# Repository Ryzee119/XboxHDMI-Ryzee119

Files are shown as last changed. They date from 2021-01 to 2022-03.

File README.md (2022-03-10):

# Original Xbox 100% Digital HDMI (Prototype)

**Note: This is a 'working' but unfinished prototype. I don't plan to improve this further. See https://makemhz.com/products/xboxhd for a properly finished product with way more features.**

* A few HDMI captures taken from this board are here: https://imgur.com/a/OkmB1Vs
* This is a prototype 100% digital Original Xbox HDMI addon PCB. It taps into the GPU pixel bus before it enters the analog video encoder and converts it to a HDMI compliant signal.
* It has not been fully tested and may not work for you. Use at your own risk. This should only really be a starting point to make something better.
* SPDIF digital audio is tapped off the Xbox motherboard and is also encoded into the HDMI signal for the best possible audio quality.
* This is a prototype board which should work on all Xbox revisions however a new flex would need to be designed to accomodate v1.6 motherboards with an Xcalibur encoder.
* 480i does not work reliably. Use a force 480p BIOS.
* The xbox kernels video modes are not compliant to proper HDMI signalling (v/hsync, porch delays etc). This does not have the ability to correct that. If your display is picky it may just not display anything.
* Currently the MakeMHz solution is recommended. https://makemhz.com/products/xboxhd. It is a completely independent design which has been much more tested and with more features.

## Bill of materials
* See [Kitspace](https://kitspace.org/boards/github.com/ryzee119/XboxHDMI-Ryzee119/).
* Flatflex must be ordered separately. See [hardware](./hardware).

## Design Files
* Source code for the STM32F0 driver is [here](./src).
* Hardware design files are [here](./hardware).

## Programming
* Compile the code with [VSCode](https://code.visualstudio.com/) and the [platformIO](https://platformio.org/install/ide?install=vscode) plugin. It should automatically create the build sytem. Just click build.
* The STM32F07 driver must be programmed with the firmware.
* Programming is through the 5 pin SWD header on the PCB. Pinout from left to right: `+3V3, SWDCLK, GND, SWDIO, NRST`
* Some debug output is via the pad labelled `TX`. Baud 115200.

## Installation

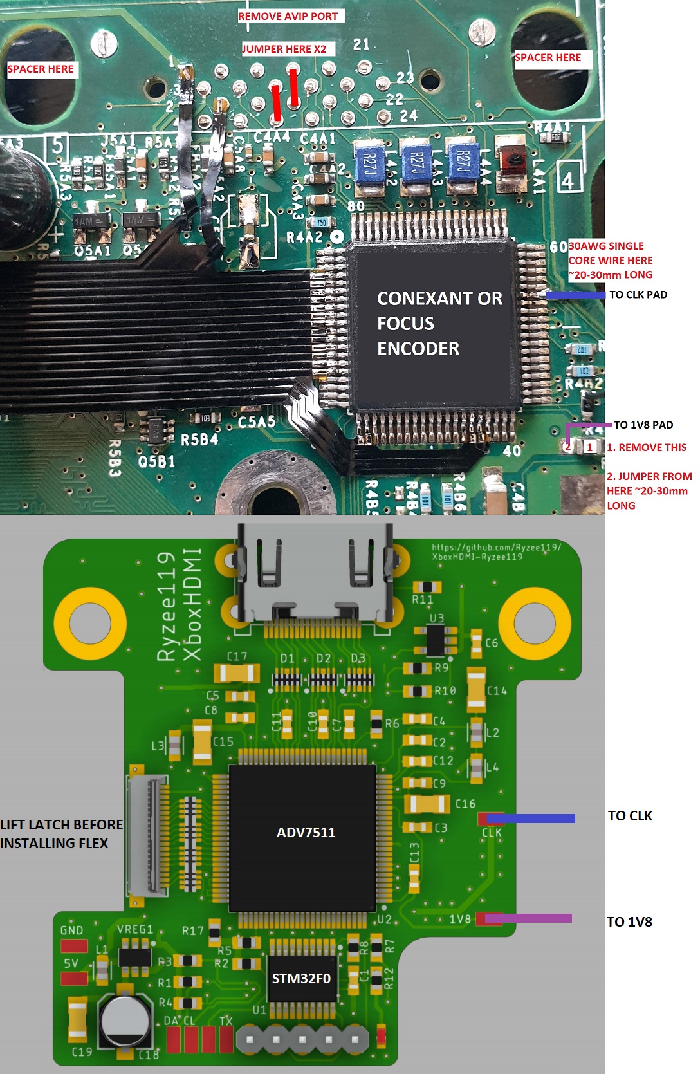
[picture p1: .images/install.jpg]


* Photo may not match final PCB layout.
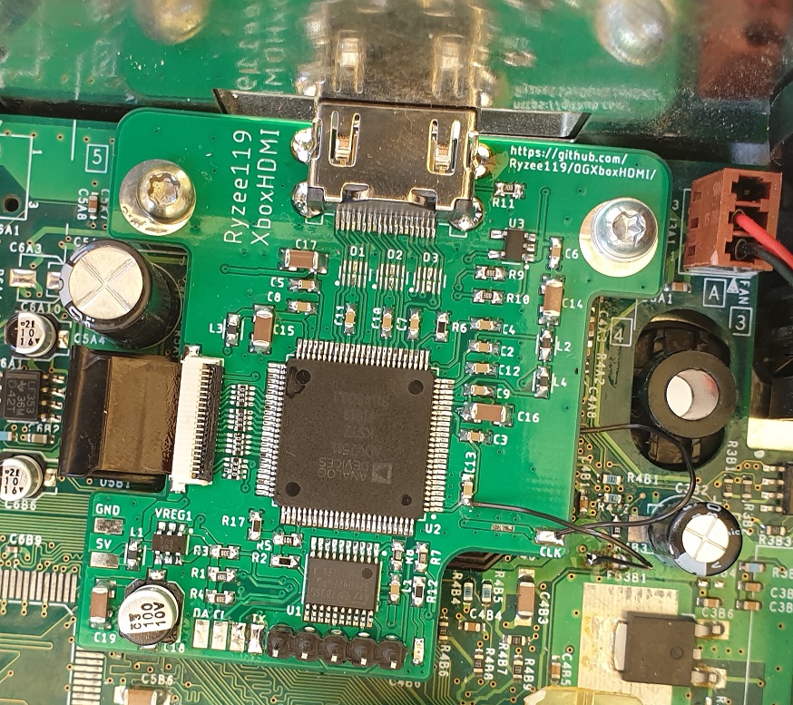
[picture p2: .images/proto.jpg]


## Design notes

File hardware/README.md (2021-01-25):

# Hardware

* This board was designed using [Autodesk Eagle](https://www.autodesk.com/products/eagle/overview). You can edit the `.brd` and `.sch` with this program.

## View Gerbers
* [XboxHDMI PCB](https://tracespace.io/view/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)
* [FlatFlex PCB](https://tracespace.io/view/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)

## View Board and Schematic
* [Board](https://a360.co/3of4zFJ)
* [Schematic](https://a360.co/2LYpuQg)

## 3D Render
* [Fusion 360](https://a360.co/2KIBkxm)

### Flat Flex Properties
* 2 Layers
* Polyimide Flex
* FPC Thickness: 0.10 mm
* Stiffener: BOTTOM Plastic : 0.20 mm , BOTTOM Fr4 : 0 mm , BOTTOM Metal : 0 mm
* Total thickness at stiffener should be 0.30 mm.
* Stiffener location: See image 

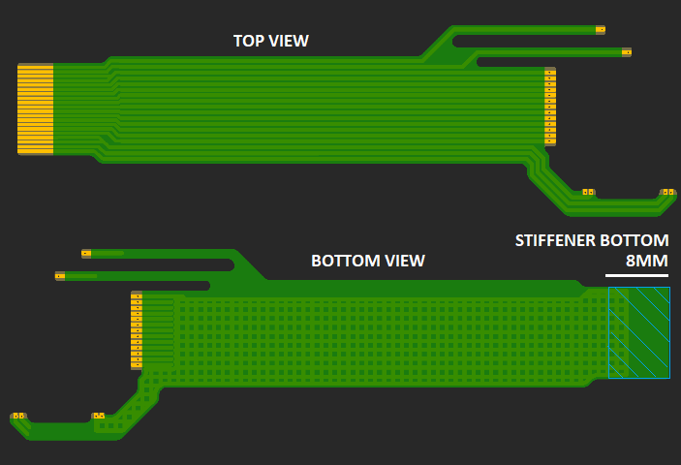
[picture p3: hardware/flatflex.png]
schematic


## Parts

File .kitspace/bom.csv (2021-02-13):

Reference | Qty | Description | Part Number | Manufacturer | Digikey
C1, C2, C3, C4, C5, C6, C7, C8, C9, C10, C11, C12, C13 | 50 | CAP CER 0.1UF 50V X7R 0603 | CL10B104KB8NNNC | Samsung Electro-Mechanics | 1276-1000-1-ND
C14, C15, C16, C17, C19 | 10 | CAP CER 10UF 16V X5R 1206 | C3216X5R1C106M160AA | TDK Corporation | 445-1426-1-ND
C18 | 1 | CAP ALUM 100UF 20% 10V SMD | UWR1A101MCL1GB | Nichicon | 493-14561-6-ND
D1, D2, D3 | 5 | TVS DIODE 5V 15V SLP2510P8 | RCLAMP0524PATCT | Semtech Corporation | RCLAMP0524PACT-ND
J1 | 1 | CONN FFC FPC 20POS 0.50MM R/A | 5034802000 | Molex | WM1445CT-ND
J2 | 1 | CONN RCPT 1.4 HDMI 19POS SMD R/A | 10029449-111RLF | Amphenol ICC (FCI) | 609-4614-1-ND
JP1 | 1 | CONN HEADER VERT 5POS 2.54MM | PH1-05-UA | Adam Tech | 2057-PH1-05-UA-ND
L1, L2, L3, L4 | 10 | FERRITE BEAD 220 OHM 0603 1LN | MPZ1608S221ATA00 | TDK Corporation | 445-1565-1-ND
LED1 | 5 | LED GREEN CLEAR 0603 SMD | 150060VS75000 | Würth Elektronik | 732-4980-1-ND
R1, R3, R4, R7, R8, R9, R10, R11 | 50 | RES SMD 2K OHM 1% 1/10W 0603 | ERJ-3EKF2001V | Panasonic Electronic Components | P2.00KHCT-ND
R13, R14, R15, R16 | 10 | RES ARRAY 4 RES 33 OHM 0804 | YC124-JR-0733RL | Yageo | YC124J-33CT-ND
R2, R6, R12, R17 | 50 | RES SMD 887 OHM 1% 1/10W 0603 | ERJ-3EKF8870V | Panasonic Electronic Components | P887HCT-ND
R5 | 50 | RES 100 OHM 1% 1/10W 0603 SMD | ERJ-U03F1000V | Panasonic Electronic Components | 10-ERJ-U03F1000VCT-ND
SPACER | 4 | ROUND SPACER 3MM HEIGHT | 005419000014 | Essentra Components | RPC3399-ND
U1 | 1 | IC MCU 32BIT 32KB FLASH 20TSSOP | STM32F070F6P6TR | STMicroelectronics | 497-17354-1-ND
U2 | 1 | ADV7511 | ADV7511KSTZ | Analog Devices
U3 | 1 | IC PWR SWITCH P-CHAN 1:1 SOT23-5 | MIC2091-1YM5-TR | Microchip Technology | 576-3891-1-ND
VREG1 | 1 | IC REG LINEAR 1.8V/3.3V SOT26 | AP7312-1833W6-7 | Diodes Incorporated | AP7312-1833W6-7DICT-ND

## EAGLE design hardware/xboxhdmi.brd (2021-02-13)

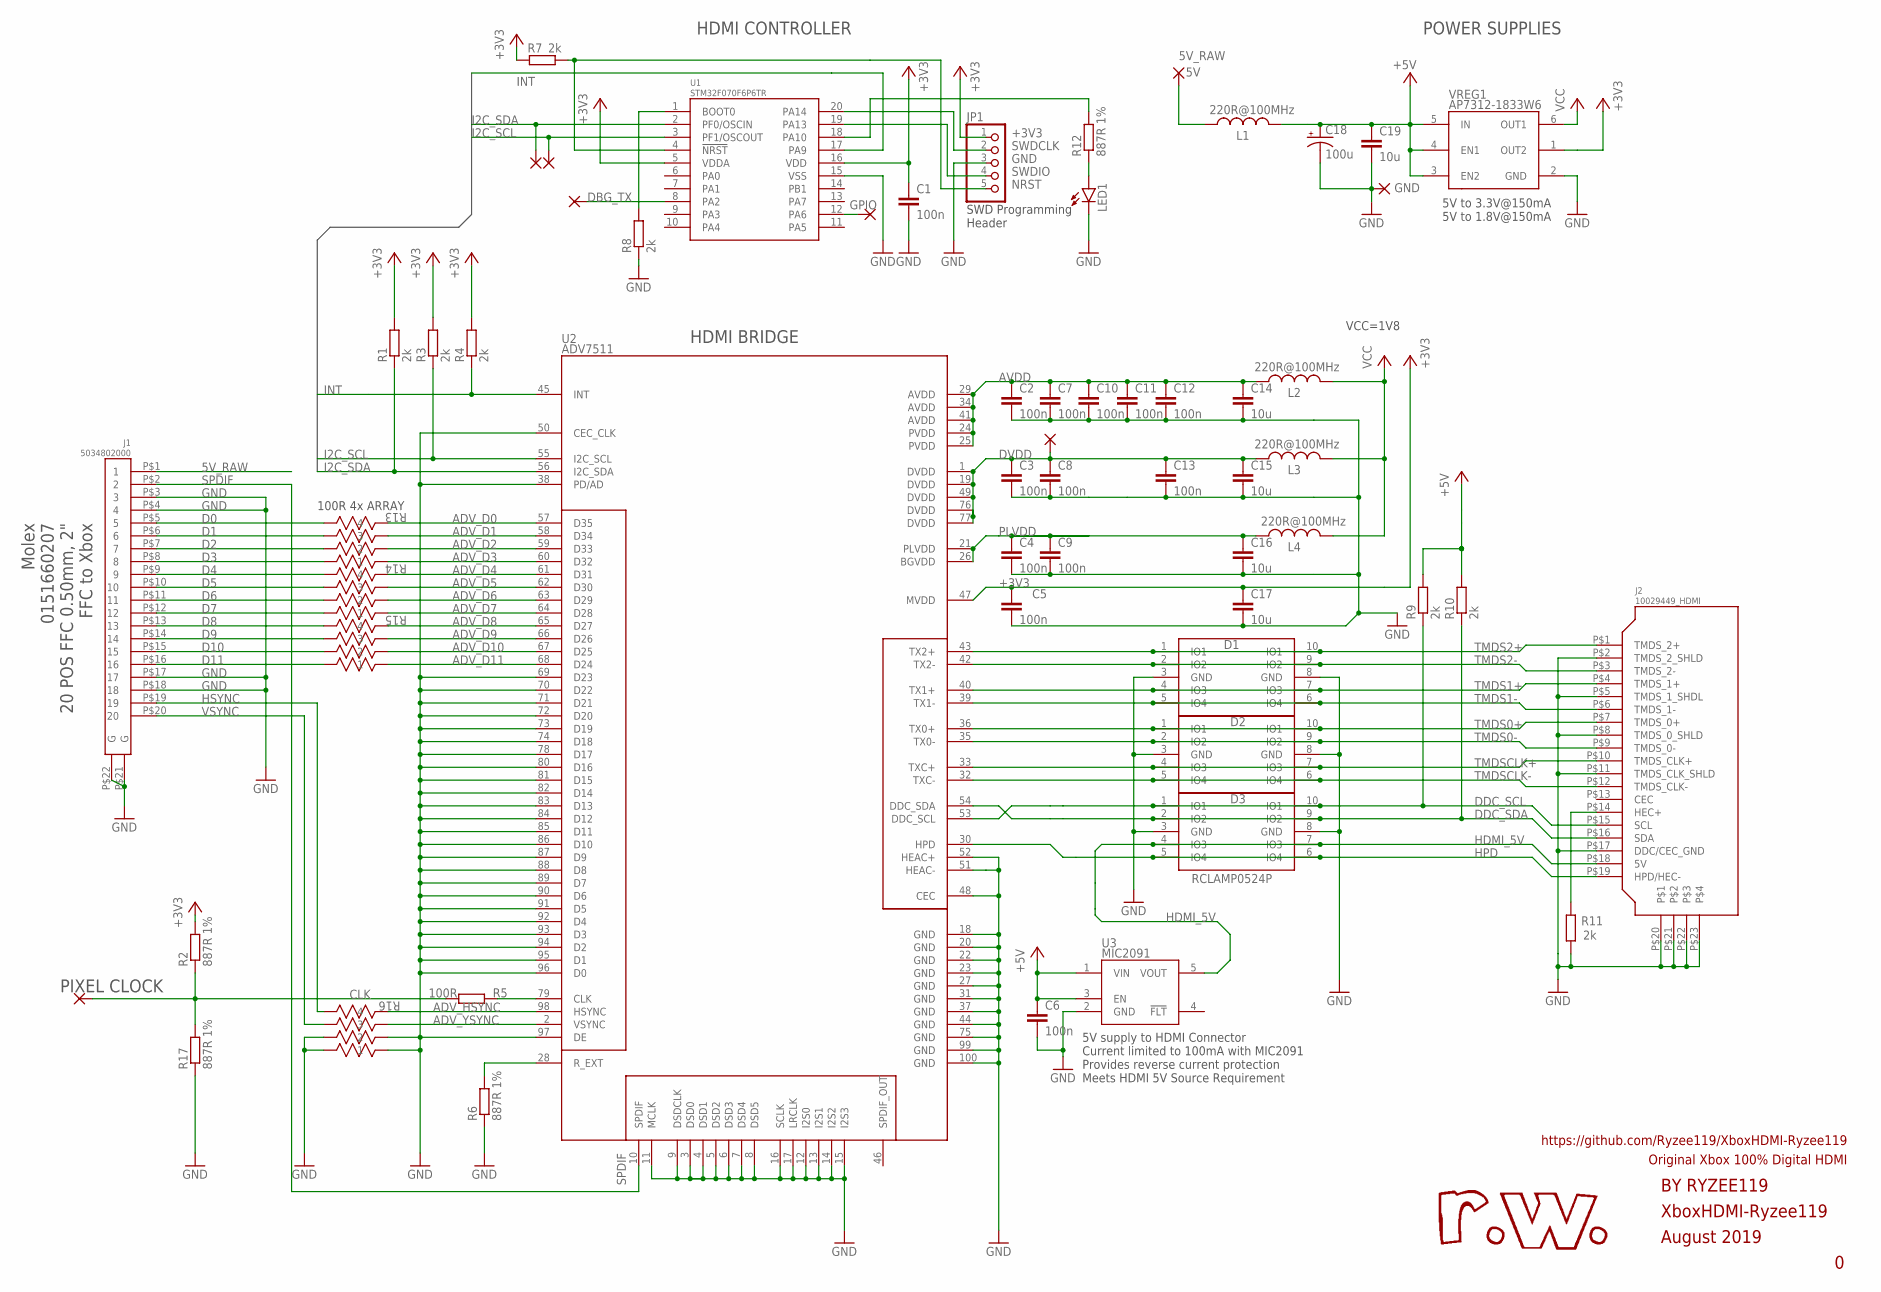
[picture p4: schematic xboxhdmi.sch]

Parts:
1V8, 5V: SMD2; SMD1,27-2,54
C1, C2, C3, C4, C5, C6, C7, C8, C9, C10, C11, C12, C13: 100n; C0603
C14, C15, C16, C17, C19: 10u; C1206
C18: 100u; 153CLV-0505
CLK: SMD2; SMD1,27-2,54
D1, D2, D3: RCLAMP0524P; DIOCAF50P250X100X65-10
GND: SMD2; SMD1,27-2,54
J1: 5034802000
J2: 10029449_HDMI; HDMI_10029449
JP1: PINHD-1X5; 1X05
L1, L2, L3, L4: 220R@100MHz; C0603
LED1: LEDCHIP-LED0603; CHIP-LED0603
PAD3, PAD4, PAD5: SMD2; SMD1,27-2,54
R1, R3, R4, R7, R8, R9, R10, R11: 2k; R0603
R2, R6, R12, R17: 887R 1%; R0603
R5: 100R; R0603
R13, R14, R15, R16: YC124-JR-0733RL; YAG_YC124
TX: SMD2; SMD1,27-2,54
U1: STM32F070F6P6TR; TSSOP20
U2: ADV7511; LQFP100
U3: MIC2091; SOT23-5
VREG1: AP7312-1833W6; SOT23-6

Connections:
5V_RAW: 5V.1, J1.P$1 (1), L1.1
+3V3: C1.1, C5.1, C17.1, JP1.1, R1.2, R2.2, R3.2, R4.2, R7.2, U1.5 (VDDA), U1.16 (VDD), U2.47 (MVDD), VREG1.1 (OUT2)
+5V: C6.1, C18.+, C19.1, L1.2, R9.2, R10.2, U3.1 (VIN), U3.3 (EN), VREG1.3 (EN2), VREG1.4 (EN1), VREG1.5 (IN)
ADV_CLK: R5.1, U2.79 (CLK)
ADV_D0: R13.4, U2.57 (D35)
ADV_D1: R13.3, U2.58 (D34)
ADV_D2: R13.2, U2.59 (D33)
ADV_D3: R13.1, U2.60 (D32)
ADV_D4: R14.4, U2.61 (D31)
ADV_D5: R14.3, U2.62 (D30)
ADV_D6: R14.2, U2.63 (D29)
ADV_D7: R14.1, U2.64 (D28)
ADV_D8: R15.4, U2.65 (D27)
ADV_D9: R15.3, U2.66 (D26)
ADV_D10: R15.2, U2.67 (D25)
ADV_D11: R15.1, U2.68 (D24)
ADV_HSYNC: R16.4, U2.98 (HSYNC)
ADV_YSYNC: R16.3, U2.2 (VSYNC)
AVDD: C2.1, C7.1, C10.1, C11.1, C12.1, C14.1, L2.1, U2.24 (PVDD), U2.25 (PVDD), U2.29 (AVDD), U2.34 (AVDD), U2.41 (AVDD)
CLK: CLK.1, R2.1, R5.2, R17.2
D0: J1.P$5 (5), R13.5
D1: J1.P$6 (6), R13.6
D2: J1.P$7 (7), R13.7
D3: J1.P$8 (8), R13.8
D4: J1.P$9 (9), R14.5
D5: J1.P$10 (10), R14.6
D6: J1.P$11 (11), R14.7
D7: J1.P$12 (12), R14.8
D8: J1.P$13 (13), R15.5
D9: J1.P$14 (14), R15.6
D10: J1.P$15 (15), R15.7
D11: J1.P$16 (16), R15.8
DBG_TX: TX.1, U1.8 (PA2)
DDC_SCL: D3.1 (IO1), D3.10 (IO1), J2.P$15 (SCL), R9.1, U2.53 (DDC_SCL)
DDC_SDA: D3.2 (IO2), D3.9 (IO2), J2.P$16 (SDA), R10.1, U2.54 (DDC_SDA)
DVDD: 1V8.1, C3.1, C8.1, C13.1, C15.1, L3.1, U2.1 (DVDD), U2.19 (DVDD), U2.49 (DVDD), U2.76 (DVDD), U2.77 (DVDD)
GND: C1.2, C2.2, C3.2, C4.2, C5.2, C6.2, C7.2, C8.2, C9.2, C10.2, C11.2, C12.2, C13.2, C14.2, C15.2, C16.2, C17.2, C18.-, C19.2, D1.3 (GND), D1.8 (GND), D2.3 (GND), D2.8 (GND), D3.3 (GND), D3.8 (GND), GND.1, J1.P$3 (3), J1.P$4 (4), J1.P$17 (17), J1.P$18 (18), J1.P$21 (G), J1.P$22 (G), J2.P$2 (TMDS_2_SHLD), J2.P$5 (TMDS_1_SHDL), J2.P$8 (TMDS_0_SHLD), J2.P$11 (TMDS_CLK_SHLD), J2.P$17 (DDC/CEC_GND), J2.P$20, J2.P$21, J2.P$22, J2.P$23, JP1.3, LED1.C, R6.1, R8.1, R11.1, R16.1, R16.2, R16.7, R16.8, R17.1, U1.15 (VSS), U2.3 (DSD0), U2.4 (DSD1), U2.5 (DSD2), U2.6 (DSD3), U2.7 (DSD4), U2.8 (DSD5), U2.9 (DSDCLK), U2.11 (MCLK), U2.12 (I2S0), U2.13 (I2S1), U2.14 (I2S2), U2.15 (I2S3), U2.16 (SCLK), U2.17 (LRCLK), U2.18 (GND), U2.20 (GND), U2.22 (GND), U2.23 (GND), U2.27 (GND), U2.31 (GND), U2.37 (GND), U2.38 (PD/AD), U2.44 (GND), U2.48 (CEC), U2.50 (CEC_CLK), U2.51 (HEAC-), U2.52 (HEAC+), U2.69 (D23), U2.70 (D22), U2.71 (D21), U2.72 (D20), U2.73 (D19), U2.74 (D18), U2.75 (GND), U2.78 (D17), U2.80 (D16), U2.81 (D15), U2.82 (D14), U2.83 (D13), U2.84 (D12), U2.85 (D11), U2.86 (D10), U2.87 (D9), U2.88 (D8), U2.89 (D7), U2.90 (D6), U2.91 (D5), U2.92 (D4), U2.93 (D3), U2.94 (D2), U2.95 (D1), U2.96 (D0), U2.97 (DE), U2.99 (GND), U2.100 (GND), U3.2 (GND), VREG1.2 (GND)
GPIO: PAD5.1, U1.12 (PA6)
HDMI_5V: D3.4 (IO3), D3.7 (IO3), J2.P$18 (5V), U3.5 (VOUT)
HEC+: J2.P$14 (HEC+), R11.2
HPD: D3.5 (IO4), D3.6 (IO4), J2.P$19 (HPD/HEC-), U2.30 (HPD)
HSYNC: J1.P$19 (19), R16.5
I2C_SCL: PAD4.1, R3.1, U1.3 (PF1/OSCOUT), U2.55 (I2C_SCL)
I2C_SDA: PAD3.1, R1.1, U1.2 (PF0/OSCIN), U2.56 (I2C_SDA)
INT: R4.1, U1.17 (PA9), U2.45 (INT)
unnamed: R12.2, U1.18 (PA10)
unnamed: LED1.A, R12.1
unnamed: R8.2, U1.1 (BOOT0)
NRST: JP1.5, R7.1, U1.4 (!NRST)
PLVDD: C4.1, C9.1, C16.1, L4.1, U2.21 (PLVDD), U2.26 (BGVDD)
R_EXT: R6.2, U2.28 (R_EXT)
SPDIF: J1.P$2 (2), U2.10 (SPDIF)
SWDCLK: JP1.2, U1.20 (PA14)
SWDIO: JP1.4, U1.19 (PA13)
TMDS0+: D2.1 (IO1), D2.10 (IO1), J2.P$7 (TMDS_0+), U2.36 (TX0+)
TMDS0-: D2.2 (IO2), D2.9 (IO2), J2.P$9 (TMDS_0-), U2.35 (TX0-)
TMDS1+: D1.4 (IO3), D1.7 (IO3), J2.P$4 (TMDS_1+), U2.40 (TX1+)
TMDS1-: D1.5 (IO4), D1.6 (IO4), J2.P$6 (TMDS_1-), U2.39 (TX1-)
TMDS2+: D1.1 (IO1), D1.10 (IO1), J2.P$1 (TMDS_2+), U2.43 (TX2+)
TMDS2-: D1.2 (IO2), D1.9 (IO2), J2.P$3 (TMDS_2-), U2.42 (TX2-)
TMDSCLK+: D2.4 (IO3), D2.7 (IO3), J2.P$10 (TMDS_CLK+), U2.33 (TXC+)
TMDSCLK-: D2.5 (IO4), D2.6 (IO4), J2.P$12 (TMDS_CLK-), U2.32 (TXC-)
VCC: L2.2, L3.2, L4.2, VREG1.6 (OUT1)
VSYNC: J1.P$20 (20), R16.6

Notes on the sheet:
VCC=1V8
5V supply to HDMI Connector Current limited to 100mA with MIC2091 Provides reverse current protection Meets HDMI 5V Source Requirement
XboxHDMI-Ryzee119
August 2019
BY RYZEE119
Original Xbox 100% Digital HDMI
https://github.com/Ryzee119/XboxHDMI-Ryzee119
SWD Programming Header
5V to 3.3V@150mA 5V to 1.8V@150mA
POWER SUPPLIES
HDMI CONTROLLER
HDMI BRIDGE
Molex 0151660207 20 POS FFC 0.50mm, 2" FFC to Xbox
PIXEL CLOCK
100R 4x ARRAY

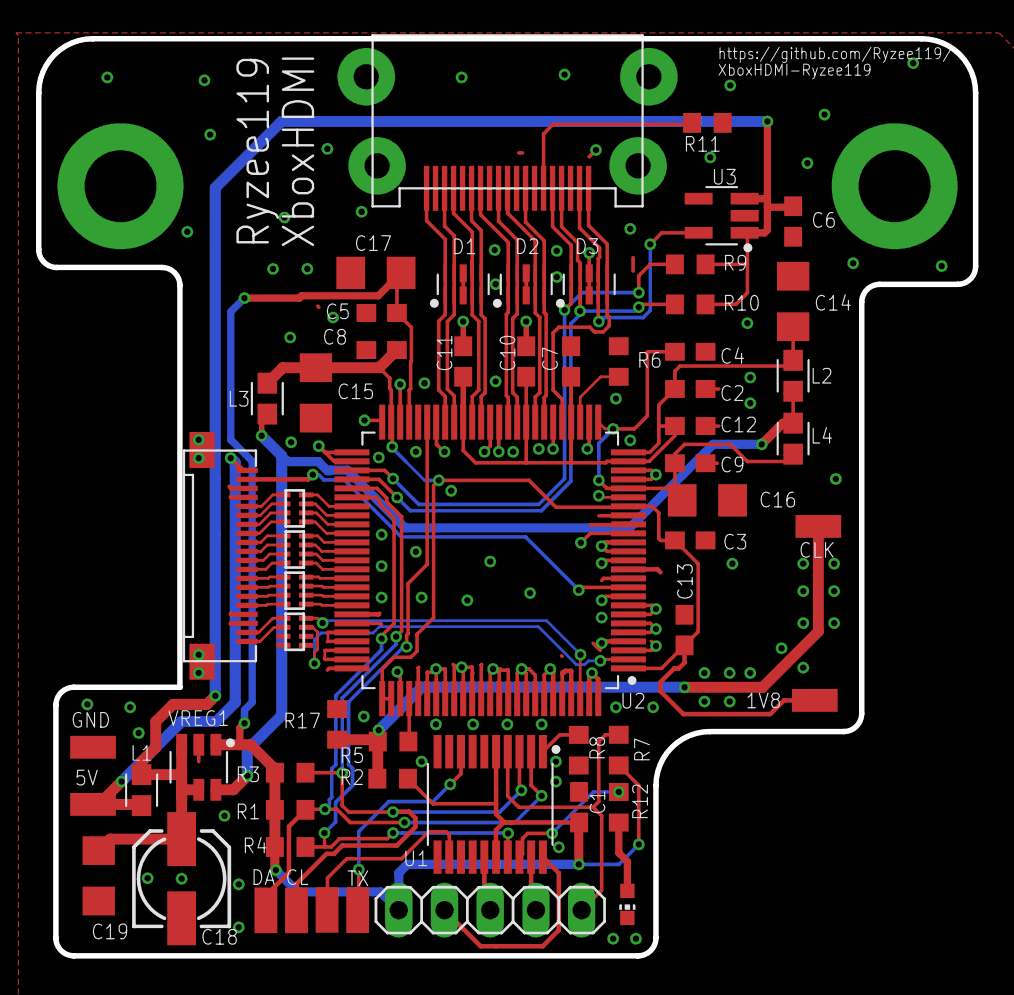
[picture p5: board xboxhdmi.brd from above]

Board: 2 copper layers, 52.0 x 51.0 mm, 59 parts (0 on the bottom side), 64 nets.

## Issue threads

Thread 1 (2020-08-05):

Progress?

TimeFlex1, 2020-08-05:
I'd this a dead project, updates?

Ryzee119, 2020-08-05:
Hello!
* The project is definitely not dead, although I have certainly been getting distracted with other projects
* I have been waiting for something to be released. Very soon.
* My long term plan is to clean up what I have and open source it all here (even in its current state, which is ~99% working)

TimeFlex1, 2020-08-05:
Hell yeah, I've been waiting for months for an update. I've been holding out from buying a Wii2Hdmi so I could do digital to digital, but I'm going to break down and go ahead and get a Wii2Hdmi and wait for your mod to come out.

Keep up the great work, looking forward to it.

TimeFlex1, 2020-08-06:
Also, I forgot to ask. Are you working on all video encoders (Conexant, Focus, and Xcalibur)?

Ryzee119, 2020-08-06:
Yes it should work on all encoders/revs

adamwtow, 2020-08-29:
Is this the same project? https://makemhz.com/products/xboxhdmi

adamwtow, 2020-08-29:
Ah found the answer (that they're different projects) in the MakeMHz Discord chat. Interesting timing.

Ryzee119, 2020-08-29:
Not my project but i have been aware of it for a long time.
They had a prototype before mine 😊

GoTeamScotch, 2020-09-14:
Looking forward to this. Thanks for all your hard work, Ryzee!

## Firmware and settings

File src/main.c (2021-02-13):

// Copyright 2021, Ryan Wendland, XboxHDMI by Ryzee119
// SPDX-License-Identifier: MIT

#include <stdio.h>
#include "main.h"
#include "stm32f0xx_hal.h"
#include "adv7511.h"

I2C_HandleTypeDef hi2c1;
UART_HandleTypeDef huart2;
adv7511 encoder;

void SystemClock_Config(void);
static void init_gpio(void);
static void init_i2c1(void);
static void init_uart2(void);

//Stdout print on UART for printf
int _write(int file, char *ptr, int len)
{
    HAL_UART_Transmit(&huart2, (uint8_t *)ptr, len, 100);
    return len;
}

int main(void)
{
    HAL_Init();
    SystemClock_Config();

    init_gpio();
    init_i2c1();
    init_uart2();

    HAL_Delay(200);
    printf("\r\nADV7511 Chip Revision %u\r\n", adv7511_read_register(&hi2c1, 0x00));

    uint8_t error = 0;

    //Initialise the encoder object
    adv7511_struct_init(&encoder);

    //Force Hot Plug Detect High
    encoder.hot_plug_detect = 1;
    error |= adv7511_write_register(&hi2c1, 0xD6, 0b11000000);

    //Power up the encoder and set fixed registers
    error |= adv7511_power_up(&hi2c1, &encoder);
    HAL_Delay(200);

    //Set video input mode to YCbCr 444, 12bit databus DDR.
    error |= adv7511_update_register(&hi2c1, 0x15, 0b00001111, 0b000000101); //ID=5

    //Set video style to style 1 (Y[3:0] Cb[7:0] first edge, Cr[7:0] Y[7:4] second edge)
    error |= adv7511_update_register(&hi2c1, 0x16, 0b00001100, 0b00001000); //style 1 01 = style 2    10 = style 1  11 = style 3

    //Set DDR Input Edge  first half of pixel data clocking edge, Bit 1 |= 0 for falling edge, 1 for rising edge CHECK
    error |= adv7511_update_register(&hi2c1, 0x16, 0b00000010, 0b00000010); //Rising

    //Bit order reverse for input signals. 1 |= LSB .... MSB Reverse Bus Order
    //Just how my PCB is layed out.
    error |= adv7511_update_register(&hi2c1, 0x48, 0b01000000, 0b01000000);

    //DDR Alignment . 1 |= DDR input is D[35:18] (left aligned), 0 = right aligned
    error |= adv7511_update_register(&hi2c1, 0x48, 0b00100000, 0b00000000);

    //Clock Delay adjust.
    error |= adv7511_update_register(&hi2c1, 0xD0, 0b10000000, 0b10000000);
    error |= adv7511_update_register(&hi2c1, 0xD0, 0b01110000, 3 << 4); //0 to 6, 3 = no delay
    error |= adv7511_update_register(&hi2c1, 0xBA, 0b11100000, 3 << 5);

    //Must be 11 for ID=5 (No sync pulse)
    error |= adv7511_update_register(&hi2c1, 0xD0, 0b00001100, 0b00001100);

    //Enable DE generation. This is derived from HSYNC,VSYNC for video active framing
    error |= adv7511_update_register(&hi2c1, 0x17, 0b00000001, 0b00000001);

    //Set Output Format to 4:4:4
    error |= adv7511_update_register(&hi2c1, 0x16, 0b10000000, 0b00000000);

    //Start AVI Infoframe Update
    error |= adv7511_update_register(&hi2c1, 0x4A, 0b01000000, 0b01000000);

    //Infoframe output format to YCbCr 4:4:4 in infoframe* 10=YCbCr4:4:4, 00=RGB
    error |= adv7511_update_register(&hi2c1, 0x55, 0b01100000, 0b01000000);

    //Infoframe output aspect ratio default to 4:3
    error |= adv7511_update_register(&hi2c1, 0x56, 0b00110000, 0b00010000);
    error |= adv7511_update_register(&hi2c1, 0x56, 0b00001111, 0b00001000);

    //END AVI Infoframe Update
    error |= adv7511_update_register(&hi2c1, 0x4A, 0b01000000, 0b00000000);

    //Output Color Space Selection 0 = RGB 1 = YCbCr
    error |= adv7511_update_register(&hi2c1, 0x16, 0b00000001, 0b00000001);

    //Set Output to HDMI Mode (Instead of DVI Mode)
    error |= adv7511_update_register(&hi2c1, 0xAF, 0b00000010, 0b00000010);

    //Enable General Control Packet CHECK
    error |= adv7511_update_register(&hi2c1, 0x40, 0b10000000, 0b10000000);

    //Disable CSC
    //error |= adv7511_update_register(&hi2c1, 0x18, 0xFF, 0x00);

    //SETUP AUDIO
    //Set 48kHz Audio clock CHECK (N Value)
    error |= adv7511_update_register(&hi2c1, 0x01, 0xFF, 0x00);
    error |= adv7511_update_register(&hi2c1, 0x02, 0xFF, 0x18);
    error |= adv7511_update_register(&hi2c1, 0x03, 0xFF, 0x00);

    //Set SPDIF audio source
    error |= adv7511_update_register(&hi2c1, 0x0A, 0b01110000, 0b00010000);

    //SPDIF enable
    error |= adv7511_update_register(&hi2c1, 0x0B, 0b10000000, 0b10000000);

    if (error)
    {
        printf("Encountered error when setting up ADV7511\r\n");
    }

    apply_csc(&hi2c1, (uint8_t *)identityMatrix);
    uint8_t vic = 0x80;
    uint8_t pll_lock = 0;

    while (1)
    {
        if (error)
        {
            printf("Encountered error when setting up ADV7511\r\n");
            error = 0;
        }

        //Check PLL status
        pll_lock = (adv7511_read_register(&hi2c1, 0x9E) >> 4) & 0x01;
        if (pll_lock == 0)
        {
            printf("PLL Lock: %u\r\n", pll_lock);
            HAL_GPIO_WritePin(GPIOA, STATUS_LED, GPIO_PIN_RESET);
        }
        else
        {
            HAL_GPIO_WritePin(GPIOA, STATUS_LED, GPIO_PIN_SET);
        }

        if ((adv7511_read_register(&hi2c1, 0x3e) >> 2) != (vic & 0x0F))
        {
            printf("VIC Changed!\r\n");
            //Set MSB to 1. This indicates a recent change.
            vic = ADV7511_VIC_CHANGED | adv7511_read_register(&hi2c1, 0x3e) >> 2;
            printf("Detected VIC#: 0x%02x\r\n", vic & ADV7511_VIC_CHANGED_CLEAR);
        }

        if (encoder.interrupt)
        {
            uint8_t interrupt_register = adv7511_read_register(&hi2c1, 0x96);
            printf("Interrupt occurred!\r\n");
            printf("interrupt_register: 0x%02x\r\n", interrupt_register);

            if (interrupt_register & ADV7511_INT0_HPD)
            {
                printf("HPD interrupt\r\n");
                encoder.hot_plug_detect = (adv7511_read_register(&hi2c1, 0x42) >> 6) & 0x01;
            }

            if (interrupt_register & ADV7511_INT0_MONITOR_SENSE)
            {
                printf("Monitor Sense Interrupt\r\n");
                encoder.monitor_sense = (adv7511_read_register(&hi2c1, 0x42) >> 5) & 0x01;
            }

            (encoder.hot_plug_detect) ? printf("HDMI cable detected\r\n") : printf("HDMI cable not detected\r\n");
            (encoder.monitor_sense) ? printf("Monitor is ready\r\n") : printf("Monitor is not ready\r\n");

            if (encoder.hot_plug_detect && encoder.monitor_sense)
            {
                adv7511_power_up(&hi2c1, &encoder);
            }

            encoder.interrupt = 0;
            //Re-enable interrupts
            adv7511_update_register(&hi2c1, 0x96, 0b11000000, 0xC0);
        }

        if (vic & ADV7511_VIC_CHANGED)
        {
            uint16_t hs_delay = 0, vs_delay = 0, active_w = 0, active_h = 0;
            uint8_t ddr_edge = 1;
            vic &= ADV7511_VIC_CHANGED_CLEAR;

            //Set pixel rep mode to auto
            //error |= adv7511_update_register(&hi2c1, 0x3B, 0b01100000, 0b00000000);

            if (vic == ADV7511_VIC_VGA_640x480_4_3)
            {
                printf("Set timing for VGA 640x480 4:3\r\n");
                //Infoframe output aspect ratio default to 4:3
                error |= adv7511_update_register(&hi2c1, 0x56, 0b00110000, 0b00010000);
                ddr_edge = 1;
                hs_delay = 119; //121
                vs_delay = 36;
                active_w = 720;
                active_h = 480;
            }

            else if (vic == ADV7511_VIC_480p_4_3 || vic == ADV7511_VIC_480p_16_9 || vic == ADV7511_VIC_UNAVAILABLE)
            {
                if (vic == ADV7511_VIC_480p_16_9)
                {
                    //Infoframe output aspect ratio default to 16:9
                    error |= adv7511_update_register(&hi2c1, 0x56, 0b00110000, 0b00100000);
                    printf("Set timing for 480p 16:9\r\n");
                }
                else
                {
                    //Infoframe output aspect ratio default to 4:3
                    error |= adv7511_update_register(&hi2c1, 0x56, 0b00110000, 0b00010000);
                    printf("Set timing for 480p 4:3\r\n");
                }
                ddr_edge = 1;
                hs_delay = 118;
                vs_delay = 36;
                active_w = 720;
                active_h = 480;
            }

            else if (vic == ADV7511_VIC_720p_60_16_9)
            {
                printf("Set timing for 720p 16:9\r\n");
                //Infoframe output aspect ratio default to 16:9
                error |= adv7511_update_register(&hi2c1, 0x56, 0b00110000, 0b00100000);
                ddr_edge = 1;
                hs_delay = 299; //259?
                vs_delay = 25;
                active_w = 1280;
                active_h = 720;
            }

            else if (vic == ADV7511_VIC_1080i_60_16_9)
            {
                printf("Set timing for 1080i 16:9\r\n");
                //Infoframe output aspect ratio default to 16:9
                error |= adv7511_update_register(&hi2c1, 0x56, 0b00110000, 0b00100000);
                //Set interlace offset
                error |= adv7511_update_register(&hi2c1, 0x37, 0b11100000, 0 << 5);
                //Offset for Sync Adjustment Vsync Placement
                error |= adv7511_update_register(&hi2c1, 0xDC, 0b11100000, 0 << 5);
                ddr_edge = 1;
                hs_delay = 233; //232
                vs_delay = 22;
                active_w = 1920;
                active_h = 540;
            }

            error |= adv7511_update_register(&hi2c1, 0x16, 0b00000010, ddr_edge << 1);
            error |= adv7511_update_register(&hi2c1, 0x36, 0b00111111, (uint8_t)vs_delay);
            error |= adv7511_update_register(&hi2c1, 0x35, 0b11111111, (uint8_t)(hs_delay >> 2));
            error |= adv7511_update_register(&hi2c1, 0x36, 0b11000000, (uint8_t)(hs_delay << 6));
            error |= adv7511_update_register(&hi2c1, 0x37, 0b00011111, (uint8_t)(active_w >> 7));
            error |= adv7511_update_register(&hi2c1, 0x38, 0b11111110, (uint8_t)(active_w << 1));
            error |= adv7511_update_register(&hi2c1, 0x39, 0b11111111, (uint8_t)(active_h >> 4));
            error |= adv7511_update_register(&hi2c1, 0x3A, 0b11110000, (uint8_t)(active_h << 4));
            printf("Actual Pixel Repetition : 0x%02x\r\n", (adv7511_read_register(&hi2c1, 0x3D) & 0xC0) >> 6);
            printf("Actual VIC Sent : 0x%02x\r\n", adv7511_read_register(&hi2c1, 0x3D) & 0x1F);
        }
    }
}

void SystemClock_Config(void)
{

    RCC_OscInitTypeDef RCC_OscInitStruct;
    RCC_ClkInitTypeDef RCC_ClkInitStruct;
    RCC_PeriphCLKInitTypeDef PeriphClkInit;

    //Initializes the CPU, AHB and APB busses clocks
    RCC_OscInitStruct.OscillatorType = RCC_OSCILLATORTYPE_HSI;
    RCC_OscInitStruct.HSIState = RCC_HSI_ON;
    RCC_OscInitStruct.HSICalibrationValue = 16;
    RCC_OscInitStruct.PLL.PLLState = RCC_PLL_NONE;
    if (HAL_RCC_OscConfig(&RCC_OscInitStruct) != HAL_OK)
    {
        _Error_Handler(__FILE__, __LINE__);
    }

    //Initializes the CPU, AHB and APB busses clocks
    RCC_ClkInitStruct.ClockType = RCC_CLOCKTYPE_HCLK | RCC_CLOCKTYPE_SYSCLK | RCC_CLOCKTYPE_PCLK1;
    RCC_ClkInitStruct.SYSCLKSource = RCC_SYSCLKSOURCE_HSI;
    RCC_ClkInitStruct.AHBCLKDivider = RCC_SYSCLK_DIV1;
    RCC_ClkInitStruct.APB1CLKDivider = RCC_HCLK_DIV1;

    if (HAL_RCC_ClockConfig(&RCC_ClkInitStruct, FLASH_LATENCY_0) != HAL_OK)
    {
        _Error_Handler(__FILE__, __LINE__);
    }

    PeriphClkInit.PeriphClockSelection = RCC_PERIPHCLK_I2C1;
    PeriphClkInit.I2c1ClockSelection = RCC_I2C1CLKSOURCE_HSI;
    if (HAL_RCCEx_PeriphCLKConfig(&PeriphClkInit) != HAL_OK)
    {
        _Error_Handler(__FILE__, __LINE__);
    }

    //Configure the Systick interrupt time
    HAL_SYSTICK_Config(HAL_RCC_GetHCLKFreq() / 1000);

    //Configure the Systick
    HAL_SYSTICK_CLKSourceConfig(SYSTICK_CLKSOURCE_HCLK);

    //SysTick_IRQn interrupt configuration
    HAL_NVIC_SetPriority(SysTick_IRQn, 0, 0);
}

/* I2C1 init function */
static void init_i2c1(void)
{

    hi2c1.Instance = I2C1;
    hi2c1.Init.Timing = 0x2000090E;
    hi2c1.Init.OwnAddress1 = 0;
    hi2c1.Init.AddressingMode = I2C_ADDRESSINGMODE_7BIT;
    hi2c1.Init.DualAddressMode = I2C_DUALADDRESS_DISABLE;
    hi2c1.Init.OwnAddress2 = 0;
    hi2c1.Init.OwnAddress2Masks = I2C_OA2_NOMASK;
    hi2c1.Init.GeneralCallMode = I2C_GENERALCALL_DISABLE;
    hi2c1.Init.NoStretchMode = I2C_NOSTRETCH_DISABLE;
    if (HAL_I2C_Init(&hi2c1) != HAL_OK)
    {
        _Error_Handler(__FILE__, __LINE__);
    }

    //Configure Analogue filter
    if (HAL_I2CEx_ConfigAnalogFilter(&hi2c1, I2C_ANALOGFILTER_ENABLE) != HAL_OK)
    {
        _Error_Handler(__FILE__, __LINE__);
    }

    //Configure Digital filter
    if (HAL_I2CEx_ConfigDigitalFilter(&hi2c1, 0) != HAL_OK)
    {
        _Error_Handler(__FILE__, __LINE__);
    }
}

static void init_uart2(void)
{

    huart2.Instance = USART2;
    huart2.Init.BaudRate = 115200;
    huart2.Init.StopBits = UART_STOPBITS_1;
    huart2.Init.Parity = UART_PARITY_NONE;
    huart2.Init.Mode = UART_MODE_TX;
    huart2.Init.HwFlowCtl = UART_HWCONTROL_NONE;
    huart2.Init.OverSampling = UART_OVERSAMPLING_16;
    huart2.Init.OneBitSampling = UART_ONE_BIT_SAMPLE_DISABLE;
    huart2.AdvancedInit.AdvFeatureInit = UART_ADVFEATURE_NO_INIT;
    if (HAL_HalfDuplex_Init(&huart2) != HAL_OK)
    {
        _Error_Handler(__FILE__, __LINE__);
    }
}

static void init_gpio(void)
{

    GPIO_InitTypeDef GPIO_InitStruct;

    //GPIO Ports Clock Enable
    __HAL_RCC_GPIOF_CLK_ENABLE();
    __HAL_RCC_GPIOA_CLK_ENABLE();
    __HAL_RCC_GPIOB_CLK_ENABLE();

    //Configure GPIO pins : PA5 PA6 PA7 (Unused)
    GPIO_InitStruct.Pin = GPIO_PIN_5 | GPIO_PIN_6 | GPIO_PIN_7;
    GPIO_InitStruct.Mode = GPIO_MODE_INPUT;
    GPIO_InitStruct.Pull = GPIO_NOPULL;
    HAL_GPIO_Init(GPIOA, &GPIO_InitStruct);

    //Configure GPIO pin : PB1 (Unused)
    GPIO_InitStruct.Pin = GPIO_PIN_1;
    GPIO_InitStruct.Mode = GPIO_MODE_INPUT;
    GPIO_InitStruct.Pull = GPIO_NOPULL;
    HAL_GPIO_Init(GPIOB, &GPIO_InitStruct);

    //Configure GPIO pins : PA10 (Status LED)
    GPIO_InitStruct.Pin = STATUS_LED;
    GPIO_InitStruct.Mode = GPIO_MODE_OUTPUT_PP;
    GPIO_InitStruct.Pull = GPIO_NOPULL;
    HAL_GPIO_Init(GPIOA, &GPIO_InitStruct);

    //Configure GPIO pin : ADV7511_INT_Pin
    GPIO_InitStruct.Pin = ADV7511_INT_Pin;
    GPIO_InitStruct.Mode = GPIO_MODE_IT_RISING_FALLING;
    GPIO_InitStruct.Pull = GPIO_NOPULL;
    HAL_GPIO_Init(ADV7511_INT_GPIO_Port, &GPIO_InitStruct);

    //EXTI interrupt init
    HAL_NVIC_SetPriority(EXTI4_15_IRQn, 0, 0);
    HAL_NVIC_EnableIRQ(EXTI4_15_IRQn);
}

void _Error_Handler(char *file, int line)
{
    while (1)
    {
    }
}

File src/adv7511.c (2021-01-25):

// Copyright 2021, Ryan Wendland, XboxHDMI by Ryzee119
// SPDX-License-Identifier: MIT

#include <string.h>
#include <stdio.h>
#include "stm32f0xx_hal.h"
#include "adv7511.h"

void adv7511_struct_init(adv7511 *encoder)
{
    encoder->hot_plug_detect = 0;
    encoder->interrupt = 0;
    encoder->monitor_sense = 0;
}

uint8_t adv7511_read_register(I2C_HandleTypeDef *i2c, uint8_t address)
{
    HAL_StatusTypeDef status;
    uint8_t register_value = 0;

    status = HAL_I2C_Mem_Read(i2c,
                              ADV7511_MAIN_I2C_ADDR,
                              address,
                              0x01,
                              &register_value,
                              0x01,
                              100);

    if (status != HAL_OK)
    {
        printf("Error with HAL_I2C_Mem_Read %u\r\n", status);
    }

    return register_value;
}

uint8_t adv7511_write_register(I2C_HandleTypeDef *i2c, uint8_t address, uint8_t value)
{
    HAL_StatusTypeDef status;
    status = HAL_I2C_Mem_Write(i2c,
                               ADV7511_MAIN_I2C_ADDR,
                               address,
                               0x01, //Memory Address Size
                               &value,
                               0x01, //Bytes to send
                               100); //Timeout (ms)
    if (status != HAL_OK)
    {
        printf("Error with HAL_I2C_Mem_Write %u\r\n", status);
        return 1;
    }

    return 0;
}

uint8_t adv7511_write_cec(I2C_HandleTypeDef *i2c, uint8_t address, uint8_t value)
{
    HAL_StatusTypeDef status;
    status = HAL_I2C_Mem_Write(i2c,
                               ADV7511_CEC_I2C_ADDR_DEFAULT,
                               address,
                               0x01, //Memory Address Size
                               &value,
                               0x01, //Bytes to send
                               100); //Timeout (ms)
    if (status != HAL_OK)
    {
        printf("Error with HAL_I2C_Mem_Write %u\r\n", status);
        return 1;
    }

    return 0;
}

uint8_t adv7511_update_register(I2C_HandleTypeDef *i2c, uint8_t address,
                                uint8_t mask, uint8_t new_value)
{
    uint8_t working_value, retval;
    uint8_t register_value = adv7511_read_register(i2c, address);

    working_value = register_value & ~mask;
    new_value &= mask;
    new_value |= working_value;

    retval = adv7511_write_register(i2c, address, new_value);

    printf("Register 0x%02x : 0x%02x -> 0x%02x\r\n",
           address, register_value, adv7511_read_register(i2c, address));

    return retval;
}

uint8_t adv7511_power_up(I2C_HandleTypeDef *i2c, adv7511 *encoder)
{
    uint8_t status;
    /* ADI recommended values for proper operation. */
    static const uint8_t add = 0, val = 1, msk = 2;

    static const uint8_t adv7511_startup[11][3] = {
        //Address, Value, Bit mask//
        {0x41, 0x00, 0b01000000},
        {0x98, 0x03, 0b11111111}, //Must be set to 0x03 for proper operation
        {0x9a, 0xe0, 0b11100000}, //Must be set to 0xe0 for proper operation
        {0x9c, 0x30, 0b11111111}, //Must be set to 0x30 for proper operation
        {0x9d, 0x01, 0b00000001}, //Must be set to 0b01 for proper operation
        {0xa2, 0xa4, 0b11111111}, //Must be set to 0xA4 for proper operation
        {0xa3, 0xa4, 0b11111111}, //Must be set to 0xA4 for proper operation
        {0xe0, 0xd0, 0b11111111}, //Must be set to 0xD0 for proper operation
        {0xf9, 0x00, 0b11111111}, //This should be set to a non-conflicting I2C address (0x00)
        {0x55, 0x01, 0b00000011}, //Set AVI info-frame to TV
        {0x96, 0xc0, 0b11000000}, //Enable HPD and Monitor Sense interrupts
    };

    if (encoder->hot_plug_detect)
    {
        for (uint8_t i = 0; i < sizeof(adv7511_startup) / 3; i++)
        {
            status = adv7511_update_register(i2c,
                                             adv7511_startup[i][add],
                                             adv7511_startup[i][msk],
                                             adv7511_startup[i][val]);

            if (status != 0)
            {
                printf("Error with HAL_I2C_Master_Transmit %u\r\n", status);
                return 1;
            }
        }
        HAL_Delay(5);
    }

    return 0;
}

uint8_t apply_csc(I2C_HandleTypeDef *i2c, uint8_t *coefficients)
{
    uint8_t error = 0;
    for (uint8_t i = 0x18; i <= 0x2F; i++)
    {
        error |= adv7511_update_register(i2c, i, 0xFF, coefficients[i - 0x18]);
    }

    return error;
}

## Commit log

2021-01-25 HW: Add board and schematic viewer links
2021-02-13 SW: Allow compilation for stm32f04
2021-02-13 HW: Remove old notes
    [xboxhdmi.sch]
2021-02-13 HW: Board cleanup
    [conex_focus_flex.brd, xboxhdmi.brd, xboxhdmi.sch]
2021-02-13 Kitspace: Add initial support
    [bom.csv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]
